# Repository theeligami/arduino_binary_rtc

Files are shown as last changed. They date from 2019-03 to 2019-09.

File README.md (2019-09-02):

## A binary real-time-clock using an Arduino Uno and a RTC_DS3231

This clock will display the time on some LEDs in binary format.
For the best results, please make sure to follow the layout plan and the schematic.

__This is a work in progress! I am not responsible for any damages to you or your property if you attempt to build this project yourself!__

____

### Requirements:
For the code to work you will need adafruit's [RTClib](https://github.com/adafruit/RTClib). Just follow their instructions to install it and you're good to go.

___

### Note:
I am also working on a wall-mount version of the clock as well as a custom pcb. Instead of a DS3231 a DCF-77 time signal receiver will be used by the new circuit.
The project will also be ported to pure C instead of Arduino C++ in the future. For more information check out the "kicad" directory.

___

### Known Issues:
__The time displayed on the clock is off or from the wrong time zone:__

This is due to the \__DATE__ variable (which is used by the DS3231) in your system being wrong. Check if your UEFI/BIOS time is set correctly.
You can set you timezone with the help of the TIMEZONE macro. TIMEZONE will be added to the hours variable.

_Feel free to report errors and bugs or give input on possible optimizations!_

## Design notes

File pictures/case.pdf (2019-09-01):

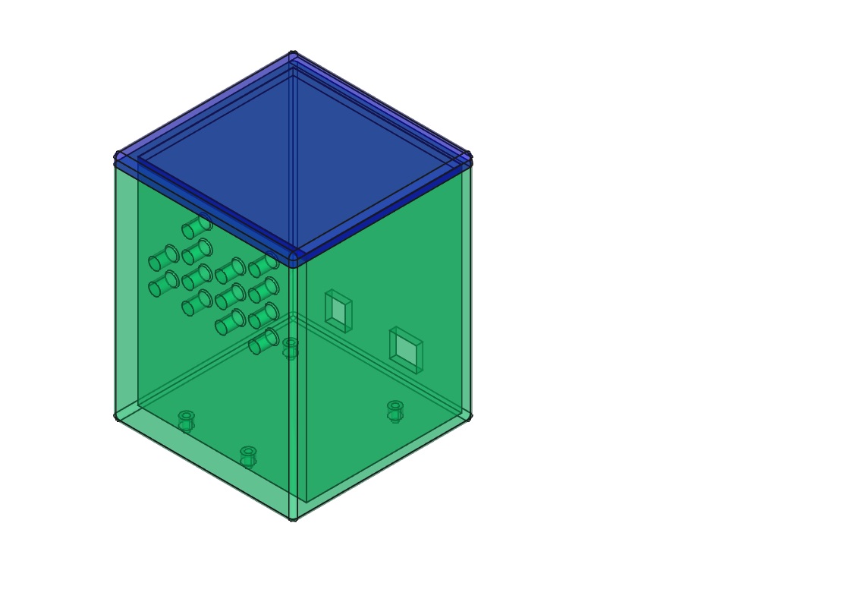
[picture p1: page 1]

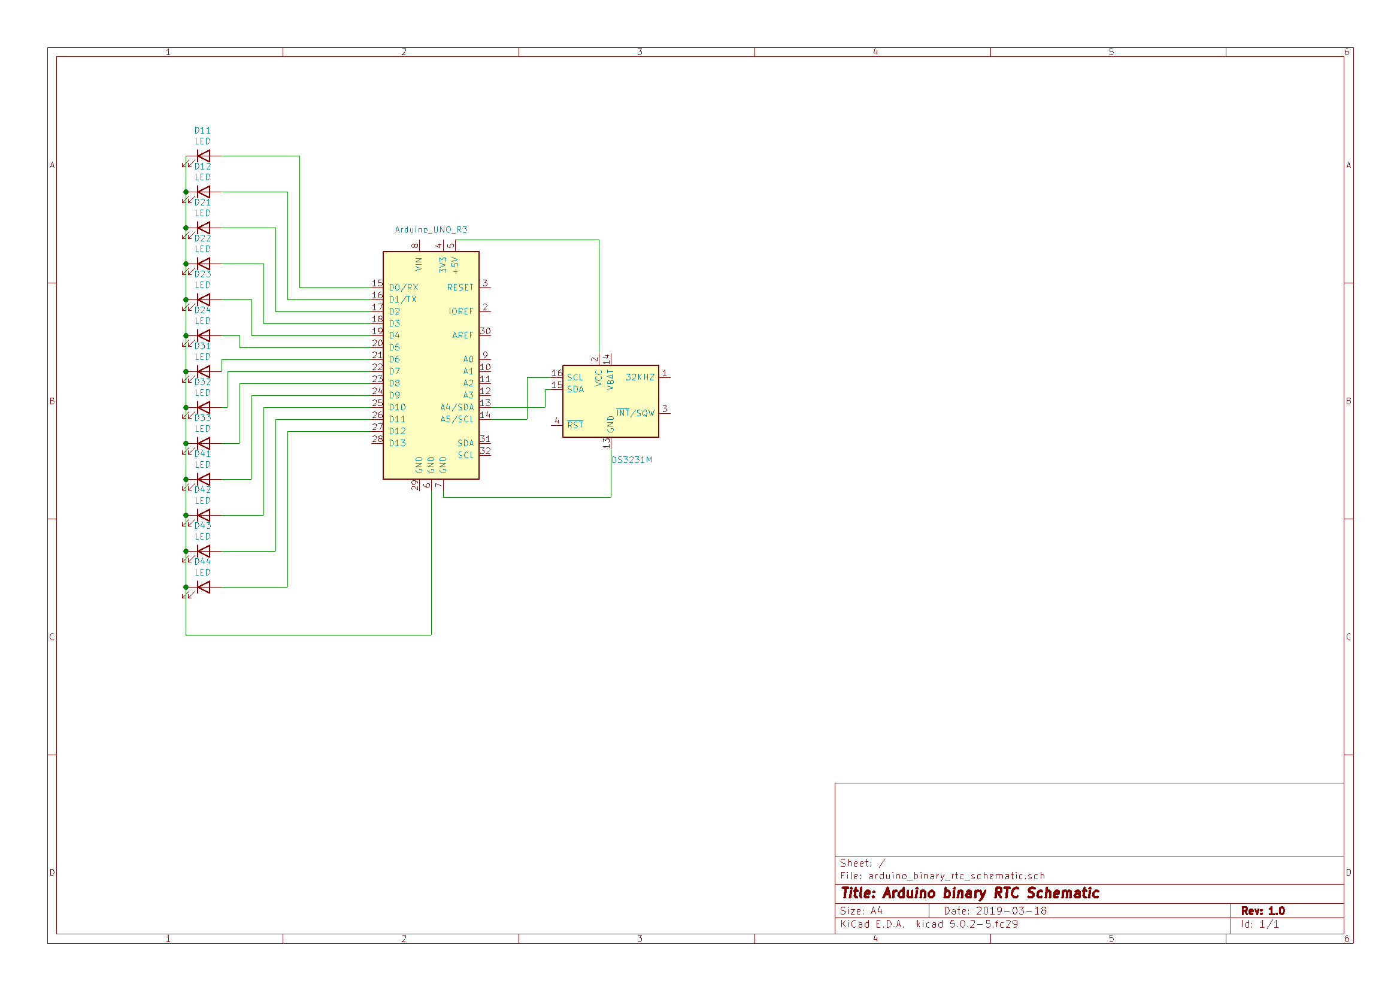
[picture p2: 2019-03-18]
pictures/schematic.png

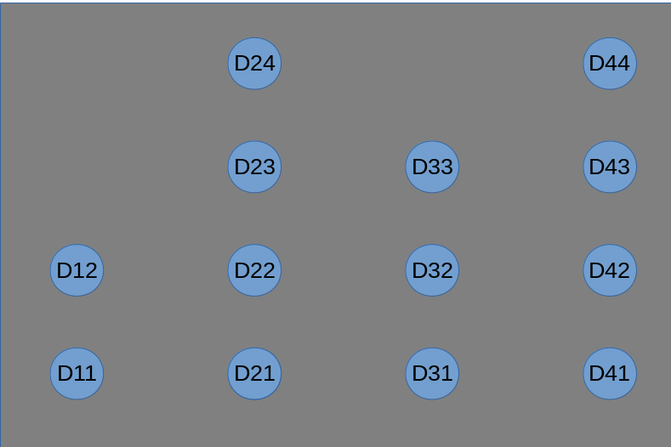
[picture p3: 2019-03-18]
pictures/led_layout.png

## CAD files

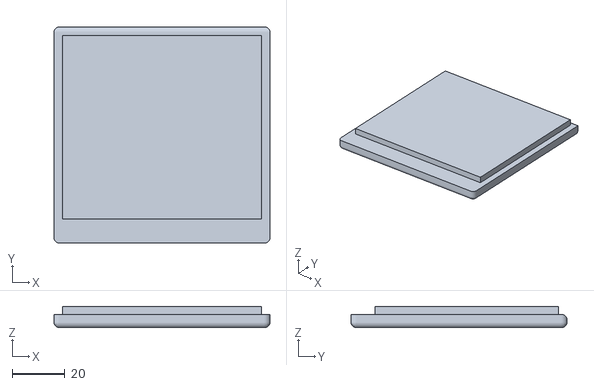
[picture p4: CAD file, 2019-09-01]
stl/case_top.stl
82.0 x 82.0 x 8.00

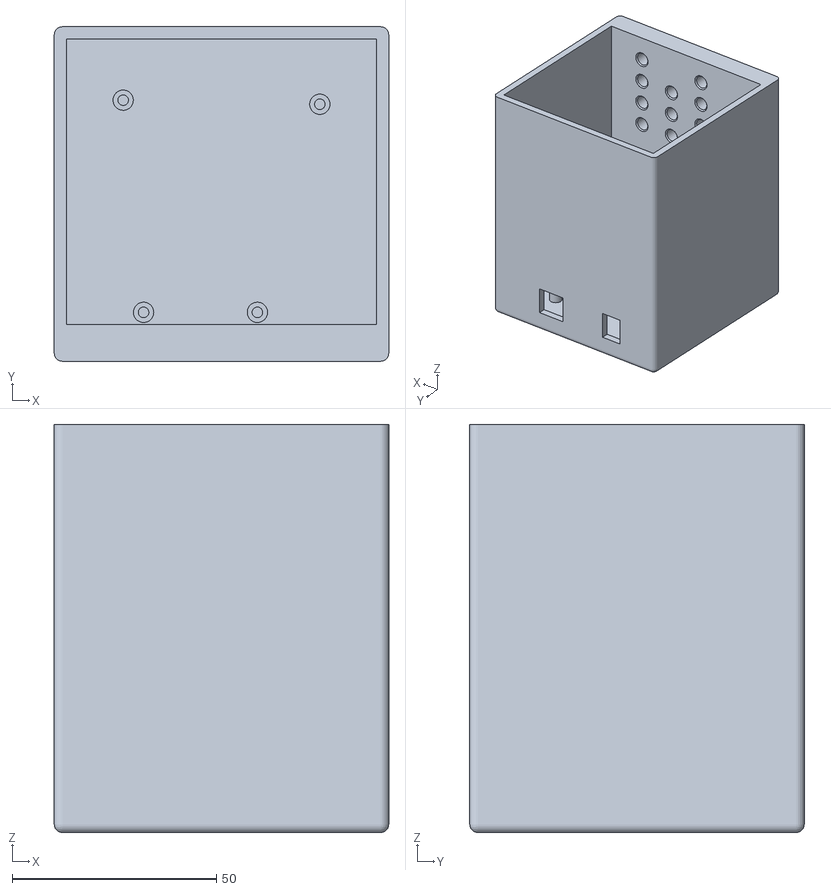
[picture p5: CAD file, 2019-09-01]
stl/case.stl
82.0 x 82.0 x 100.0

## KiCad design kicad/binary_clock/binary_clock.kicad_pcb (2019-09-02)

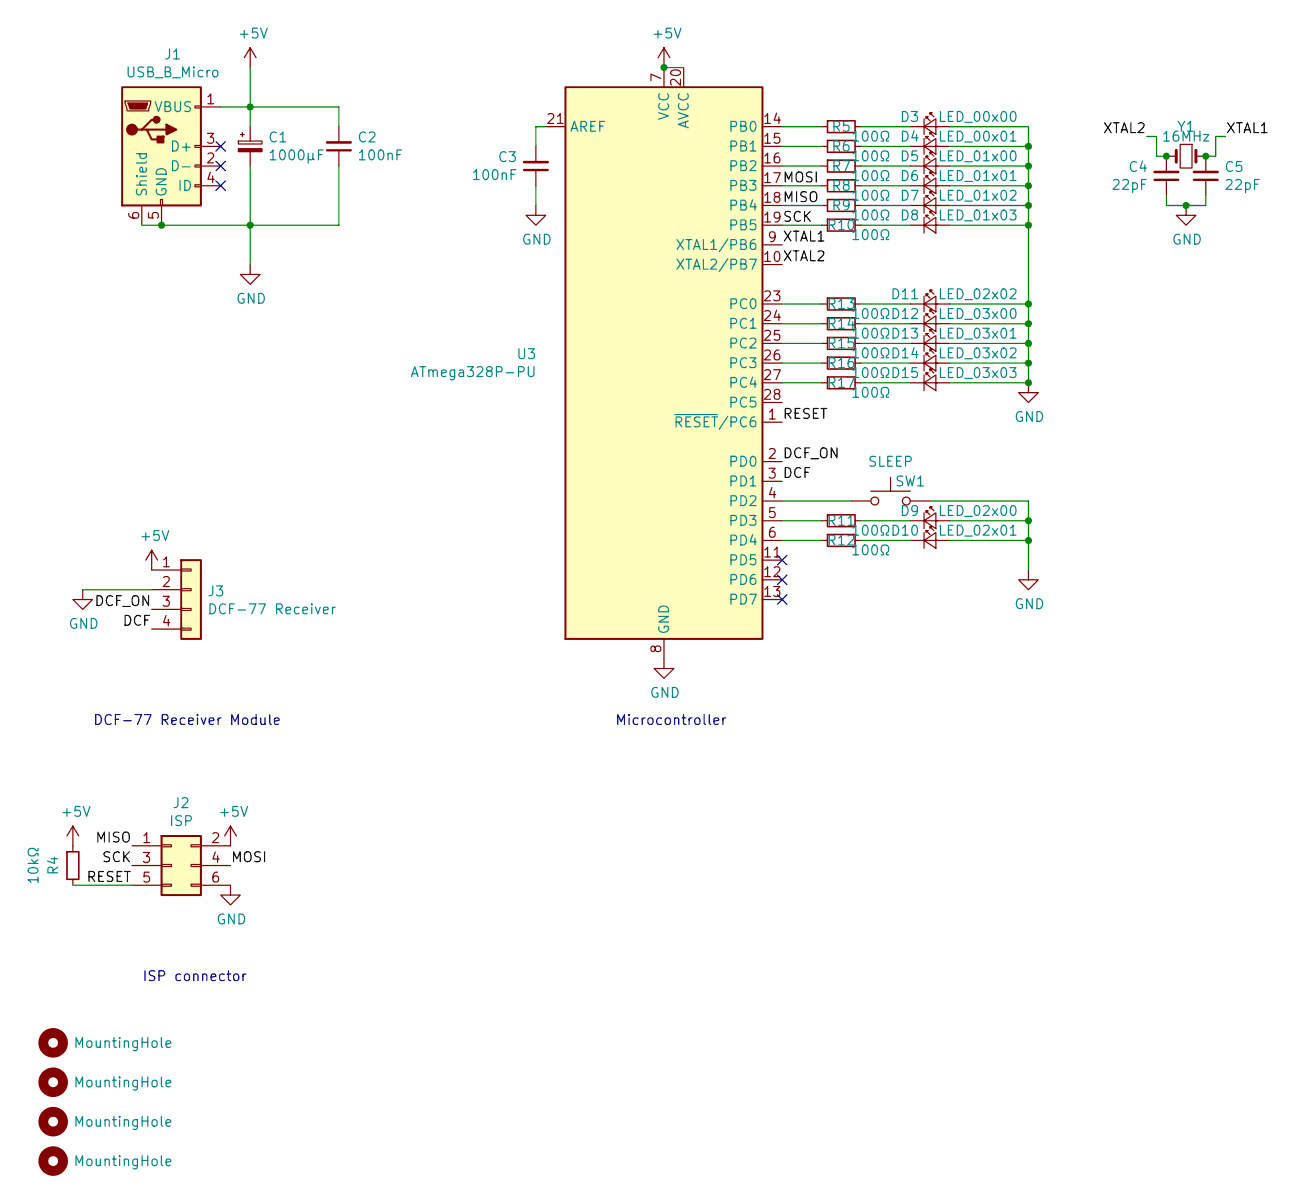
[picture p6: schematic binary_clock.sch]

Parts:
C1: 1000µF; CP_Elec_10x10
C2, C3: 100nF; C_0805_2012Metric_Pad1.15x1.40mm_HandSolder
C4, C5: 22pF; C_0805_2012Metric_Pad1.15x1.40mm_HandSolder
D3: LED_00x00; LED_D5.0mm
D4: LED_00x01; LED_D5.0mm
D5: LED_01x00; LED_D5.0mm
D6: LED_01x01; LED_D5.0mm
D7: LED_01x02; LED_D5.0mm
D8: LED_01x03; LED_D5.0mm
D9: LED_02x00; LED_D5.0mm
D10: LED_02x01; LED_D5.0mm
D11: LED_02x02; LED_D5.0mm
D12: LED_03x00; LED_D5.0mm
D13: LED_03x01; LED_D5.0mm
D14: LED_03x02; LED_D5.0mm
D15: LED_03x03; LED_D5.0mm
H1, H2, H3, H4: MountingHole; MountingHole_3.2mm_M3
J1: USB_B_Micro; USB_Mini-B_Lumberg_2486_01_Horizontal
J2: ISP; PinHeader_2x03_P2.00mm_Vertical
J3: DCF-77 Receiver; PinSocket_1x04_P2.00mm_Vertical
R4: 10kΩ; R_0805_2012Metric
R5, R6, R7, R8, R9, R10, R11, R12, R13, R14, R15, R16, R17: 100Ω; R_0805_2012Metric
SW1: SLEEP; SW_PUSH_6mm
U3: ATmega328P-PU; DIP-28_W7.62mm
Y1: 16MHz; Crystal_HC49-U_Vertical

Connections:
+5V: C1.1, C2.2, J1.1 (VBUS), J2.2, J3.1, R4.1, U3.7 (VCC), U3.20 (AVCC)
/DCF: J3.4, U3.3 (PD1)
/DCF_ON: J3.3, U3.2 (PD0)
/MISO: J2.1, R9.1, U3.18 (PB4)
/MOSI: J2.4, R8.1, U3.17 (PB3)
/RESET: J2.5, R4.2, U3.1 (~RESET~/PC6)
/SCK: J2.3, R10.1, U3.19 (PB5)
/XTAL1: C5.2, U3.9 (XTAL1/PB6), Y1.1
/XTAL2: C4.2, U3.10 (XTAL2/PB7), Y1.2
GND: C1.2, C2.1, C3.1, C4.1, C5.1, D3.2 (A), D4.2 (A), D5.2 (A), D6.2 (A), D7.2 (A), D8.2 (A), D9.2 (A), D10.2 (A), D11.2 (A), D12.2 (A), D13.2 (A), D14.2 (A), D15.2 (A), J1.5 (GND), J1.6 (Shield), J2.6, J3.2, SW1.2, U3.8 (GND), U3.22 (GND)
unnamed: C3.2, U3.21 (AREF)
unnamed: D3.1 (K), R5.2
unnamed: D4.1 (K), R6.2
unnamed: D5.1 (K), R7.2
unnamed: D6.1 (K), R8.2
unnamed: D7.1 (K), R9.2
unnamed: D8.1 (K), R10.2
unnamed: D9.1 (K), R11.2
unnamed: D10.1 (K), R12.2
unnamed: D11.1 (K), R13.2
unnamed: D12.1 (K), R14.2
unnamed: D13.1 (K), R15.2
unnamed: D14.1 (K), R16.2
unnamed: D15.1 (K), R17.2
unnamed: R5.1, U3.14 (PB0)
unnamed: R6.1, U3.15 (PB1)
unnamed: R7.1, U3.16 (PB2)
unnamed: R11.1, U3.5 (PD3)
unnamed: R12.1, U3.6 (PD4)
unnamed: R13.1, U3.23 (PC0)
unnamed: R14.1, U3.24 (PC1)
unnamed: R15.1, U3.25 (PC2)
unnamed: R16.1, U3.26 (PC3)
unnamed: R17.1, U3.27 (PC4)
unnamed: SW1.1, U3.4 (PD2)

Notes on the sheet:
Microcontroller
ISP connector
DCF-77 Receiver Module

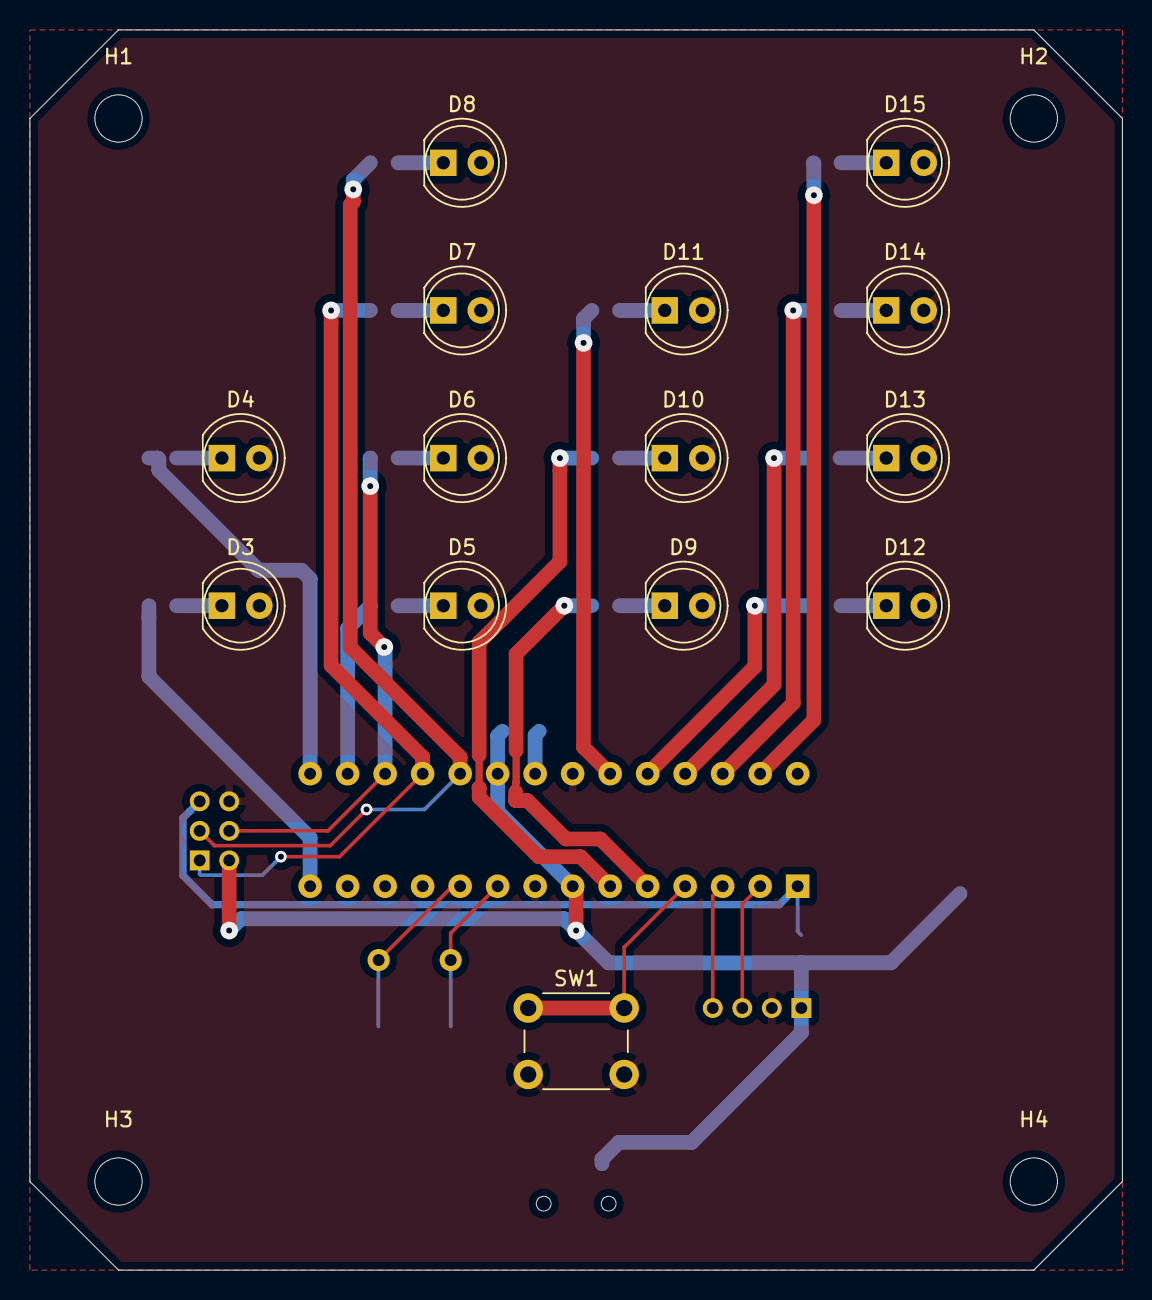
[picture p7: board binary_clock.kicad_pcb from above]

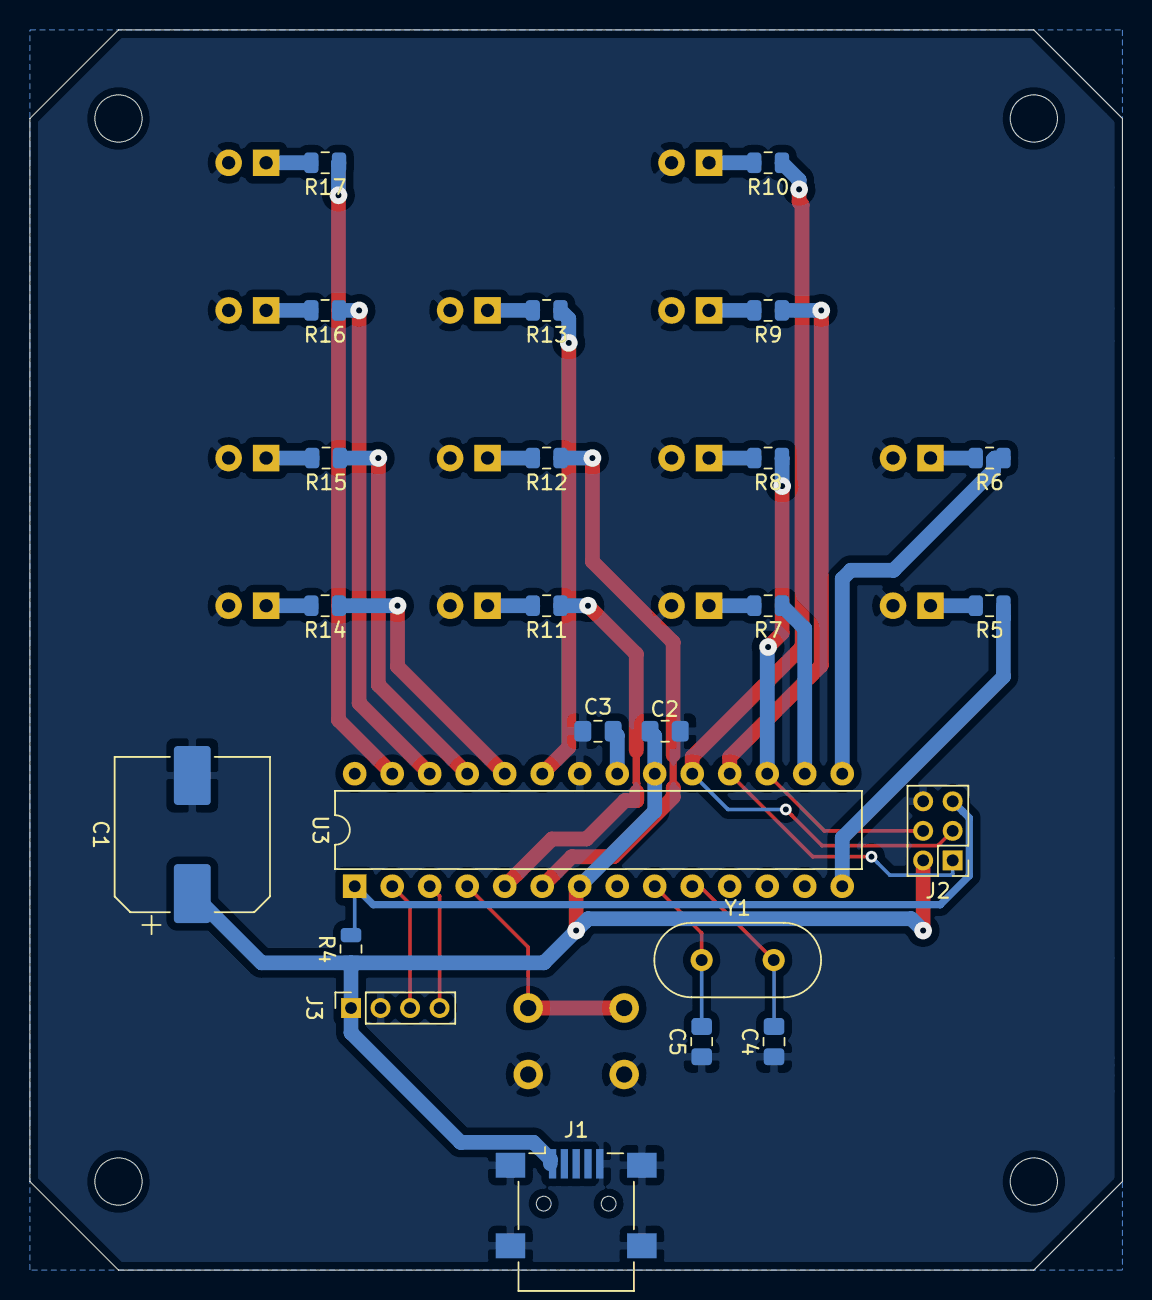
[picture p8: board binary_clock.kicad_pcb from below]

Board: 2 copper layers, 74.0 x 84.0 mm, 42 parts (24 on the bottom side), 35 nets.

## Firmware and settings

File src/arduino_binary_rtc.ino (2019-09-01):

/*
<A binary realtime clock using a DST3231_RTC-chip>
Copyright (C) <2019>  <Elias Kleimeier>

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
You should have received a copy of the GNU General Public License
along with this program.  If not, see <https://www.gnu.org/licenses/>.
*/

/*
 * Pins connections:
 * D11 - D12: first hour digit, first column from the left, numbered bottom to top
 * D21 - D24: second hour digit, second column from the left, numbered bottom to top
 * D31 - D33: first minute digit, third column from the left, numbered bottom to top
 * D41 - D44: second minute digit, fourth column from the left, numbered bottom to top
 */

#include <Wire.h>
#include "RTClib.h"

RTC_DS3231 rtc;

#define TIMEZONE 1

// First hour digit
#define D11 0
#define D12 1
// Second hour digit
#define D21 2
#define D22 3
#define D23 4
#define D24 5
// First minute digit
#define D31 6
#define D32 7
#define D33 8
// Second minute digit
#define D41 9
#define D42 10
#define D43 11
#define D44 12

const int hourPins[6] = {D11, D12, D21, D22, D23, D24};
const int minutePins[7] = {D31, D32, D33, D41, D42, D43, D44};

void setup() 
{
  Serial.begin(9600);
  delay(3000); // Wait for console opening

  if (! rtc.begin()) 
  {
    Serial.println("Couldn't find RTC");
    while (1);
  }

  if (rtc.lostPower())
  {
    Serial.println("RTC lost power, lets set the time!");
    // following line sets the RTC to the date & time this sketch was compiled
    rtc.adjust(DateTime(F(__DATE__), F(__TIME__)));
  }
    
  // Set LED pins to OUTPUT
  for (int i = 0; i < 13; i++)
  {
    pinMode(i, OUTPUT);
  }
  Serial.end(); // RX and TX needed for LEDs instead of serial
}

void loop()
{
  DateTime now = rtc.now();

  int adjHour = (now.hour() + TIMEZONE) % 24;
  
  int hour1 = adjHour / 10;      // D1X
  int hour2 = adjHour % 10;      // D2X
  int minute1 = now.minute() / 10;  // D3X
  int minute2 = now.minute() % 10;  // D4X
  
  // First hour digit
  for (int c = 1, k = 0; c >= 0; c--) 
  {
    k = hour1 >> c;

    if (k & 1) 
    {
      digitalWrite(hourPins[c], HIGH);
    }
    else 
    {
      digitalWrite(hourPins[c], LOW);
    }
  }

  // Second hour digit
  for (int c = 3, k = 0; c >= 0; c--) 
  {
    k = hour2 >> c;

    if (k & 1) 
    {
      digitalWrite(hourPins[c + 2], HIGH);
    }
    else 
    {
      digitalWrite(hourPins[c + 2], LOW);
    }
  }
  
  // First minute digit
  for (int c = 2, k = 0; c >= 0; c--) 
  {
    k = minute1 >> c;

    if (k & 1) 
    {
      digitalWrite(minutePins[c], HIGH);
    }
    else 
    {
      digitalWrite(minutePins[c], LOW);
    }
  }
  
  // Second minute digit
  for (int c = 3, k = 0; c >= 0; c--) 
  {
    k = minute2 >> c;

    if (k & 1) 
    {
      digitalWrite(minutePins[c + 3], HIGH);
    }
    else 
    {
      digitalWrite(minutePins[c + 3], LOW);
    }
  }
}

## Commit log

2019-03-18 Edited names of LEDXX macros to DXX
2019-03-18 Added schematic
2019-03-18 Layout for LED setup
2019-03-18 New LED-Layout, changed format
2019-09-01 Reorganized files. Added stl files for case.
    [case.stl, case_top.stl]
2019-09-02 Designed PCB and schematic for a custom board to fit into the wall mount version of the case.
    [binary_clock.kicad_pcb, binary_clock.sch]
2019-09-02 Added Quarz Oscillator.
    [binary_clock.kicad_pcb, binary_clock.sch]
2020-07-01 Fuck this shit
    [binary_clock.kicad_pcb, binary_clock.sch, case.stl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]

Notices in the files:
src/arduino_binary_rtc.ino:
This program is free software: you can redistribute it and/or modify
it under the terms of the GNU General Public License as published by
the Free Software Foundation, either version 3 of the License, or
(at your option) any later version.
